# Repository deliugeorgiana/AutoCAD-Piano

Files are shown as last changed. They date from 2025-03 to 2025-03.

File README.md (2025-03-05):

# AutoCAD-Piano
This project features a detailed 3D model of an upright piano, created in AutoCAD. 
It includes both external components and internal mechanisms, offering a realistic representation of the instrument's structure. 

📌 Key Features:

Detailed 3D model of an upright piano
Includes external components (case, keys, pedals)
Includes internal components (hammers, strings, dampers)
Realistic rendering for a clear visualization
The project was created to explore the technical design of a piano and improve 3D modeling skills in AutoCAD.

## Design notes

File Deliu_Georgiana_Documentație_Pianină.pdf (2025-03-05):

UNIVERSITATEA DIN BUCUREȘTI

FACULTATEA DE MATEMATICĂ ȘI INFORMATICĂ

DEPARTAMENTUL CALCULATOARE ȘI TEHNOLOGIA INFORMAȚIEI

PROIECT

PROIECTARE ASISTATĂ DE CALCULATOR

COORDONATOR ȘTIINȚIFIC

LECTOR DR. DRĂGAN MIHĂIȚĂ

STUDENT:

DELIU GEORGIANA

BUCUREȘTI, 2024

UNIVERSITATEA DIN BUCUREȘTI

FACULTATEA DE MATEMATICĂ ȘI INFORMATICĂ

DEPARTAMENTUL CALCULATOARE ȘI TEHNOLOGIA INFORMAȚIEI

PIANINĂ

(PIAN VERTICAL)

COORDONATOR ȘTIINȚIFIC

LECTOR DR. DRĂGAN MIHĂIȚĂ

STUDENT:

DELIU GEORGIANA

BUCUREȘTI, 2024

Cuprins

### 1. Introducere

### 1.1. Aplicație

Proiectul ”Pianină” a fost realizat in aplicația Autodesk AutoCAD 2024. Salvarea

fișierelor a fost făcută în fișiere tip .dwg, în versiunea Autocad 2018 (OP – Options > Open

and Save > Save as: AutoCAD 2018/LT2018 Drawing).

1.2.Motivație

Conform lui Tom Lehrer, ”Viața este ca un pian. Ce obții din ea depinde de modul

în care o joci". Aceasta este o afirmație profundă ce deschide o poartă spre reflecție și

introspecție asupra modului în care ne trăim viețile. Asemănarea dintre viață și un pian

sugerează că suntem protagoniștii propriei noastre povești, iar felul în care ne gestionăm

alegerile și acțiunile determină rezultatele pe care le obținem. Acesta este și motivul pentru

care am învățat să cânt la acest instrument, care te face să te simți fericit, indiferent de ce ți

se întâmplă în viața cotidiană.

În această optică, construirea unei pianine devine o alegere simbolică în care voi

putea explora și înțelege mai profund mesajul acestui citat. Prin proiectarea unei pianine,

voi intra într-o relație directă cu procesul de creație și cu ideea de a da viață unui instrument

muzical, voi fi ca un pianist care își compune propriul său concert. Fiecare pas în construcția

pianinei reprezintă o notă muzicală în partitura vieții umane. Alegerea mărimilor si a layer-

elor reflectă alegerile și valorile mele, precum și felul în care vreau să-mi exprim esența și

aspirațiile.

Prin această experiență, avem de invățat că viața nu este doar despre a trăi pasiv, ci

despre a fi creatori activi ai propriului nostru destin. La fel cum un pianist trebuie să practice

și să-și perfecționeze abilitățile pentru a interpreta o melodie frumoasă, și noi trebuie să fim

dedicați în a ne dezvolta și îmbunătăți în mod continuu.

Construirea unei pianine îmi va oferi, de asemenea, ocazia de a mă conecta cu

muzica într-un mod mai profund, deaorece voi învăța despre mecanismele interne ale

acestui instrument muzical, fiecare componentă contribuind la întregul armonios al

acesteia.

Prin experiența de a crea, ne amintim că suntem cei care conducem orchestra vieții

noastre și că frumusețea și armonia depind de modul în care interpretăm partitura noastră

personală.

1.3.Istoric

Pianina (Fig.1) - o variantă mai mică a pianoforte-ului (Fig.2). La rândul său,

clavicordul și clavecinul sunt considerate a fi predecesorii pianoforte-ului. Acest instrument

a fost creat special pentru muzică de cameră în spații mici. Pianul - în italiană "pianino" -

se traduce ca "un pian mic". Spre deosebire de pianul original, în cazul pianinei, coardele,

cutia de rezonanță și mecanismul sunt dispuse vertical, astfel încât ocupă mult mai puțin

spațiu în cameră. Și acest lucru este important, deoarece în timp, instrumentele și muzica

au devenit mai accesibile populației obișnuite. Datorită dimensiunilor compacte, sunetul

pianului este mai puțin puternic decât cel al pianului de concert. Primul pian a fost creat în

1709 de către meșterul italian Bartolomeo Cristofori. El a luat ca bază carcasa clavecinului

și mecanismul de taste al clavicordului. Acest eveniment a dus la apariția pianului.

Figură 1.1. Pianină [1]

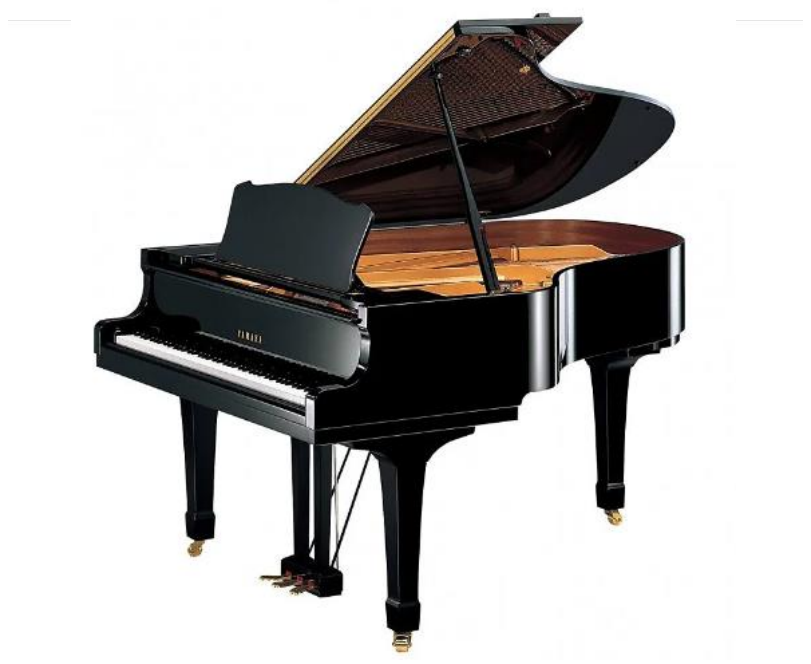
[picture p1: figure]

Figură 1.2. Pianoforte [2]
În anul 1800, americanul J. Hawkins a inventat prima pianină din lume. În 1801, o

construcție similară, dar deja cu pedale, a fost creată de către M. Müller din Australia. Cu

toate acestea, pianina arăta complet diferit pe atunci, față de modul în care societatea îl

cunoaște acum. Forma modernă a fost adoptată de abia la mijlocul secolului al XIX-lea.

Pianina a fost atât de iubită, încât acest instrument a continuat să fie îmbunătățit timp de aproape trei sute de ani. În secolul al XX-lea, au apărut pianul electronic și

sintetizatorul, cunoscute multora. Se pare că, odată cu nașterea acestui instrument, s-au născut și artiștii care să creeze capodopere pe el. În orice caz, pentru ca muzica acestui

instrument neobișnuit să aducă plăcere, trebuie să îl iubim, să îl simțim, să îl înțelegem.

Ideea unui pian vertical a apărut ca o evoluție a designului pianului. În timp ce pianul

cu coadă era preferat pentru calitățile sale sonore și performanțele de concert, acesta era

uneori prea mare și prea costisitor pentru spațiile mai mici sau pentru cei care nu puteau să

își permită un pian cu coadă.

În secolele care au urmat, diferiți constructori de instrumente muzicale au continuat

să îmbunătățească și să dezvolte designul pianinei. În secolul al XIX-lea, avansările

tehnologice și inovațiile în construcția instrumentelor au permis producția în masă a

pianinelor, făcându-le accesibile unui număr mai mare de oameni. Tot atunci, a apărut și

pianul ”Girafă” (Fig.1.3).

Un moment crucial în istoria pianinei a fost introducerea mecanismului de acțiune directă

(Fig.1.4) în anii 1820, ceea ce a îmbunătățit semnificativ calitatea sunetului și a făcut pianina mai

plăcută și mai ușor de jucat. Această inovație a condus la popularitatea crescândă a pianinei ca

instrument de uz casnic și în sălile de clasă.

Figură 1.3. Pianul "Girafa" [3]

Figură 1.4. Mecanism de acțiune [4]

Astfel, istoricul pianinei reflectă o evoluție continuă a acestui instrument muzical, de la

primele sale apariții până în prezent, adaptându-se cerințelor și tendințelor din domeniul muzical

și al designului instrumentelor.

### 2. Proiectarea pianinei

2.1.Setare Layere

Am creat 36 Straturi, care pot fi vizualizate în tabelul de mai jos:

Nr. Layer | Nume Layer | Culoare Layer | Stil linie | Grosime linie
1. | Clapă albă 2D | 254 | Continuă | 1 mm
2. | Clapă albă 3D | 255 | Continuă | 1 mm
3. | Clapă neagră 2D | 251 | Continuă | 1 mm
4. | Clapă neagră 3D | 250 | Continuă | 1 mm
5. | Corp principal 2D | 31 | Continuă | 1 mm
6. | Corp principal 3D | 17 | Continuă | 1 mm
7. | Mecanism de închidere 2D | 201 | Continuă | 1 mm
8. | Mecanism de închidere 3D | 215 | Continuă | 1 mm
9. | Pedală 2D | 151 | Continuă | 1 mm
10. | Pedală 3D | 167 | Continuă | 1 mm
11. | Roată 2D | 211 | Continuă | 1 mm
12. | Roată 3D | 45 | Continuă | 1 mm
13. | Scăunel | 15 | Continuă | 1 mm
14. | Sârmă de mână 2D | 51 | Continuă | 1 mm
15. | Sârmă de mână 3D | 50 | Continuă | 1 mm
16. | Mecanism de acțiune 2D | 33 | Continuă | 1 mm
17. | Mecanism de acțiune 3D | 35 | Continuă | 1 mm
18. | Material amortizator | 84 | Continuă | 1 mm
19. | Linguriță amortizatoare | 51 | Continuă | 1 mm
20. | Coardă 2D | 31 | Continuă | 1 mm
21. | Coardă 3D | 41 | Continuă | 1 mm
22. | Șurub 2D | 21 | Continuă | 1 mm
23. | Șurub 3D | 11 | Continuă | 1 mm
24. | Bară de presiune 2D | 111 | Continuă | 1 mm

25. | Bară de presiune 3D | 110 | Continuă | 1 mm
26. | Zăbrele acordare 2D | 131 | Continuă | 1 mm
27. | Zăbrele acordare 3D | 140 | Continuă | 1 mm
28. | Punte lungă 2D | 202 | Continuă | 1 mm
29. | Punte lungă 3D | 192 | Continuă | 1 mm
30. | Pini de ancorare 2D | 241 | Continuă | 1 mm
31. | Pini de ancorare 3D | 243 | Continuă | 1 mm
32. | Cadru 2D | 91 | Continuă | 1 mm
33. | Cadru 3D | 93 | Continuă | 1 mm
34. | Placă de rezonanță 2D | 41 | Continuă | 1 mm
35. | Placă de rezonanță 3D | 43 | Continuă | 1 mm
36. | DEFPOINTS | 171 | Continuă | 1 mm

### 2.2. Componente externe

Înainte de a începe această lucrare, am setat Workspace-ul pe ”Drafting and Annotation”,

am deselectat opțiunea de salvare automată, cu ajutorul funcției (Options > Open and Save >

deselectare Automatic Save), iar după aceea am schmibat unitățile în măsura de centimetri

(UNITS > cemtimeters).

Figură 2.1 Setare UNITS

Figură 2.2. Setarea Workspace-ului

### 2.2.1. Clapa albă și clapa neagră

Am început să lucrez, făcând schița 2D a unei clape albe și a uneia negre, cu dimensiunile

luate de la pianul meu. Inițial am făcut clapa albă, folosind Layer-ul ”Clapă albă 2D”, cu funcția

Rectangle, prima latură având lungimea de 14,5 cm, iar cea de-a doua 2,3 cm (RECTANGLE >

14.5 > Tab > 2.3 > Enter). După aceea, am setat Layer-ul ”Clapă neagră 2D”, și utilizând funcția

OFFSET, la o distanță de 0,5 cm față de latura stângă a dreptunghiului alb, am creat o linie de

ajutor. (OFFSET > 0.5 > Apasăm pe linia din partea stângă > O mutăm în partea stângă > Enter).

Acum, din colțul de sus al liniei de ajutor , cu ajutorul funcției Rectangle facem un dreptunghi

cu dimensiunile 1 cm și 9 cm (RECTANGLE > 1 > Tab > 9 > Enter). Pentru a putea fi văzute

toate dimensiunile în figură, am utilizat funcția LINEAR.

După ce am terminat schița 2D, am schimbat Worksapce-ul în 3D Basics și am schimbat

Layerul de lucru în ”Clapă albă 3D”. Pentru a delimita obiectul, am utilizat funcția

BOUNDARY(BOUNDARY > REGION > Selectăm mijlocul schiței > Enter). Lățimea clapei

albe este de 2 cm. Am folosit funcția EXTRUDE (EXTRUDE > Selectăm dreptunghiul mare >

2 > Enter). Acum selectăm stratul ”Clapă neagră 3D”. Pentru a delimita obiectul, am utilizat

funcția BOUNDARY(BOUNDARY > REGION > Selectăm mijlocul schiței > Enter). Lățimea

clapei negre este de 1 cm. Folosim funcția EXTRUDE (EXTRUDE > Selectăm dreptunghiul

mare > 1 > Enter).

Figura 2.3. Clapa albă și clapa neagră 2D

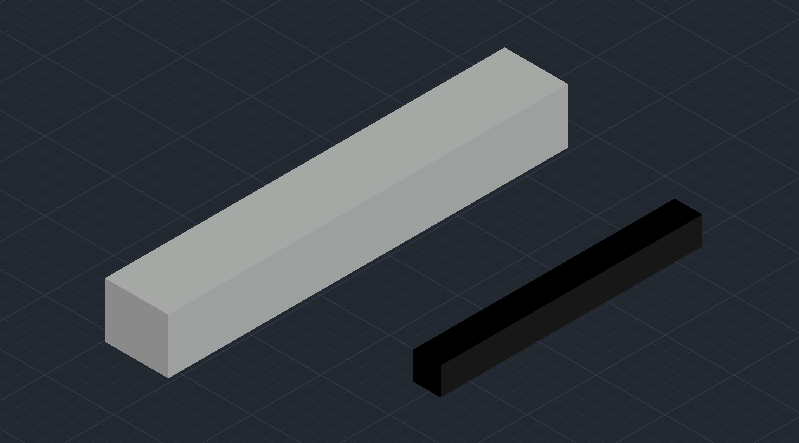
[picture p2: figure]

### 2.2.2. Placă superioară

Înainte de a mă apuca de lucru, am creat cele 2 Layere pe care le-am folosit mai apoi. Primul

a fost ”Corp principal 2D”. Cu ajutorul funcției RECTANGLE, am creat un dreptunghi, prima

latură având lungimea de 19 cm, iar cea de-a doua 150 cm (RECTANGLE > 19 > Tab > 150 >

Enter). Am selectat Layer-ul ”Element de distanțare” și am apăsat pe funcția OFFSET, plecând de

la latura inferioară de 150 cm a dreptunghiului, pe o distanță de 1cm (OFFSET > 1 > Apasăm pe

latura inferioară a dreptunghiului > O mutăm în jos > Enter). După aceea, folosin funcția LINE,

unim capetele cu cele ale dreptunghiului (LINE > 1 > , > 90). Mai folosim încă o dată funcția

OFFSET, dar de data aceasta, de la linia de jos, în sus, pe o distanță de 1 cm (OFFSET > 1 >

Apăsăm pe linia de jos > O mutăm în sus > Enter). Setăm iar Layer-ul ”Corp principal 2D”, folosim

OFFSET pe o distanță de 0,5 cm față de ultima linie și o tragem în sus (OFFSET > 0.5 > Apăsăm

pe ultima linie folosită > O mutăm în sus > Enter). Cu ajutorul funcției MIRROR, selectăm

dreptunghiul de sus, și îl oglindim față de noua linie creată (MIRROR > Selectăm entitatea

dreptunghi > Space > Selectăm Middle Point > Space > Fixăm entitatea oglindită > No > Enter). Ștergem linia de ajutor cu ajutorul comenzii ERASE. În final, am adăugat și dimensiunile, care pot

fi observate și în figura 2.5.

Figura 2.4 Clapa albă și clapa neagră 3D

FIgura 2.5. Placă superioară 2D

După ce am terminat schița 2D, am schimbat Worksapce-ul în 3D Basics și am schimbat

Layerul de lucru,”Corp principal 3D”. Pentru a delimita obiectul, am utilizat funcția BOUNDARY

(BOUNDARY > REGION > Selectăm mijlocul schiței > Enter). Lățimea obiectului este de 1 cm,

iar a celui din mijloc de 1.3 cm. Am folosit funcția EXTRUDE (EXTRUDE > Selectăm conturul

> 1 > Selectăm dreptunghiul mic > 1.3 > Enter).

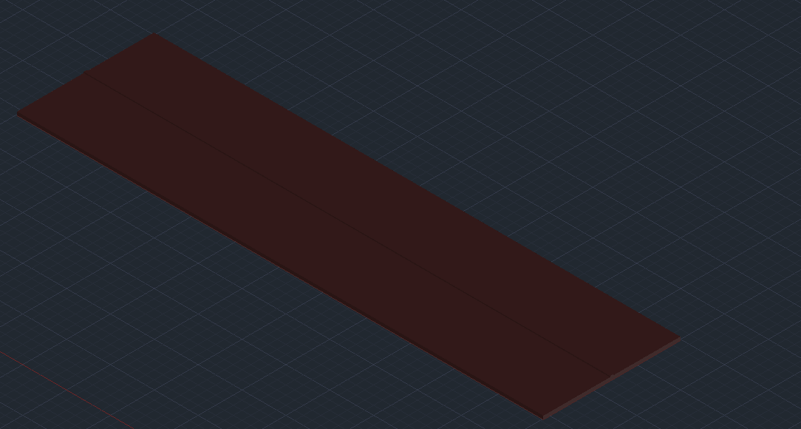
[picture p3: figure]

Figură 2.6. Placă superioară 3D

### 2.2.3. Capac

Înainte de a începe să fac schița 2D, am setat Straturile ”Corp principal 2D” și ”Mecanism de

închidere 2D”. Pentru a face viziunea frontală, am început cu un dreptungi (RECTANGLE > 135

> Tab > 20 > Enter). Am folosit funcția EXPLODE, spărgând astfel dreptunghiul în 4 bucăți.

Pentru a mai trasa o linie de lungimea celei de sus, am utilizat funcția OFFSET (OFFSET > 2 >

Apasăm pe linia de sus > O mutăm în jos > Enter). La o distanță de 4 cm față de linia de jos, am creat un dreptunghi. (RECTANGLE > 42 > Tab > 2 > Enter). În dreapta acestui dreptunghi, am făcut altul. (RECTANGLE > 4 > Tab > 1 > Enter). Pentru a face același dreptunghi și pe partea

stângă, am utilizat funcția MIRROR (MIRROR > Selectăm entitatea dreptunghi > Space >

Selectăm Middle Point > Space > Fixăm entitatea oglindită > No > Enter). Selectăm stratul

”Mecanism de închidere 2D” și între cele două linii de sus, facem un dreptunghi (RECTANGLE > 1 > Tab > 8 > Enter). În interiorul acestuia, facem alt dreptunghi (RECTANGLE > 0.4 > Tab >2 >

Enter). La o distanță de 0.6 cm față de latura din drepata a dreptunghiului exterior, am facut un

cerc (CIRCLE > RADIUS > 0.2 > Enter). Cu ajutorul funției MIRROR, l-am oglindit (MIRROR

> Selectăm entitatea cerc > Space > Selectăm Middle Point > Space > Fixăm entitatea oglindită >

No > Enter). Finalizând aceste acțiuni, am obținut vederea din față a capacului.

Figura 2.7. Capac 2D, Vedere frontală

Pentru a face vederea laterală, am selectat stratul ”Corp principal 2D”. Cu ajutorul funcției

POLYLINE, am creeat urmatoarea entitate. (POLYLINE > 2 > Space > 5 > Space > 18 > Space >

2 > Space > 20 > Space > 7). La o distanță de 7 cm începând de la bază, am făcut un dreptunghi

(RECTANGLE > 1 > Tab > 7 > Enter). Folosind funcția OFFSET, trasăm niște linii (OFFSET >

0,5 > Apasăm pe linia din capătul stâng > O mutăm în dreapta > Enter > Repetăm). Pentru a mai

trasa o linie, folosim aceeași funcție (OFFSET > 1 > Apasăm pe linia din dreapta > O mutăm în

stânga > Enter). La o distanță de 3.05 față de latura dreaptă, facem un dreptunghi (RECTANGLE

> 0.2 > Tab > 0.9 > Enter). La o distanță de 1 cm față de mijlocul inferior al dreptunghiului, copiem

entitatea în stânga și în drepata (COPY > Selectăm dreptunghiul > 1 > Enter).

Figura 2.8. Capac 2D, Vedere laterală

După ce am terminat schița 2D, am schimbat Worksapce-ul în 3D Basics și am schimbat

Layerul de lucru, și anume ” Corp principal 3D”. Pentru a delimita toate zonele necesare, am utilizat

funcția BOUNDARY (BOUNDARY > REGION > Selectăm toate zonele desenului > Enter).

Vederea laterală ne este de ajutor pentru a vedea lățimea obiectelor, astfel începem să înalțăm toate

piesele.Pentru partea de sus, folosim următoarea funcție (PRESSPULL > 7 >Space > Space > 7.5

> Space > 7.5 > Space > 7.5). Pentru partea de jos (PRESSPULL > 2 > Space > 7 > Space > 7 >

Space > 7). Pentru a adăuga și suportul de portativ, facem un dreptunghi (RECTANGLE > 2 > Tab

> 42 > Enter). După aceea, îl copiem, pentru a mai forma 2 dreptunghiuri asemănătoare (COPY >

Selectăm dreptunghiul > 2 > Enter > Repetăm). După aceea, le selectăm și utilizăm functia

3DROTATE, la un unghi de 90°. Cu ajutorul funcției MOVE, selectăm cele 3 dreptungiuri și le

mutăm. După aceea, folosim functia EXTRUDE, la nivel de 0.5 cm.

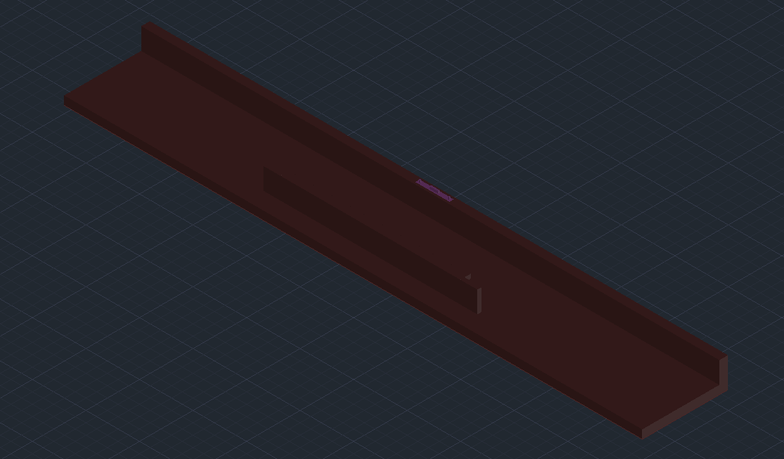
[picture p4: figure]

Figura 2.9. Capac 3D

### 2.2.4. Braț lateral

Am schimbat Workspace-ul în Drafting & Annotation, am setat stratul ” Corp principal 2D ”.

Pentru viziunea laterală am utilizat funcția POLYLINE (POLYLINE > 12 > Space > 30 > Space >

17 > Space > 2.5 > Space > 5 > Space > 2.5 > Space > 25 > Enter). Pentru a face o zonă rotunjită,

folosim funcția TAN, TAN, RADIUS, cu raza cercului de 7 cm. (TAN > TAN > 7 > rotunjită,

folosim funcția TAN, TAN, RADIUS, cu raza cercului de 7 cm. (TAN > TAN > 7 > Enter). Pentru

a rotunji zona din partea de stânga sus, folosim funcția FILLET (FILLET > r > 3 > Enter).

Figura 2.10. Braț lateral 2D, Vedere lateral

Pentru a face vederea frontală, am utilizat funcția de dreptunghi (RECTANGLE > 17 > Tab > 4 >Enter).

Figura 2.11. Braț lateral 2D, Vedere Frontală

După ce am terminat schița 2D, am schimbat Worksapce-ul în 3D Basics și am schimbat Layerul

de lucru, ” Corp principal 3D ”. Pentru a delimita obiectul, am utilizat funcția

BOUNDARY(BOUNDARY > REGION > Selectăm mijlocul schiței > Enter). Vederea laterală ne

este de ajutor pentru a vedea lățimea acestui obiect, și anume de 4 cm. Am folosit funcția

EXTRUDE (EXTRUDE > Selectăm obiectul > 4 > Enter). Pentru a roti obiectul, am folosit funcția

3DROTATE (Selectăm obiectul > Apelăm funcția 3DROTATE > Ridicăm pe verticală la 90° >

Rotim pe orizontală spre dreapta la 90° > Enter).

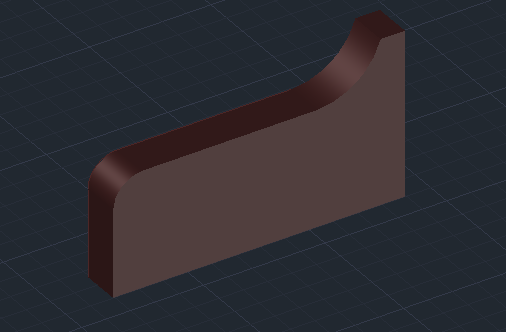
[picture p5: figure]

Figura 2.12. Braț lateral 3D

### 2.2.5. Placă laterală

Am schimbat Workspace-ul în Drafting & Annotation, am setat stratul ” Corp principal 2D

”. Pentru viziunea laterală am utilizat funcția POLYLINE (POLYLINE > 55 > Space > 118 > Space

> 35 > Space > 109 > Space > 20 > Space > 9 > Enter ). Pentru a face vederea frontală, am utilizat

funcția de dreptunghi (RECTANGLE > 118 > Tab > 1 >Enter).

Figura 2.13. Placă laterală 2D

După ce am terminat schița 2D, am schimbat Worksapce-ul în 3D Basics și am schimbat Layerul

de lucru, ” Corp principal 3D ”. Pentru a delimita obiectul, am utilizat funcția

BOUNDARY(BOUNDARY > REGION > Selectăm mijlocul schiței > Enter). Vederea laterală ne

este de ajutor pentru a vedea lățimea acestui obiect, și anume de 1 cm. Am folosit funcția

EXTRUDE (EXTRUDE > Selectăm obiectul > 1 > Enter). Pentru a roti obiectul, am folosit funcția

3DROTATE (Selectăm obiectul > Apelăm funcția 3DROTATE > Ridicăm pe verticală la 90° >

Rotim pe orizontală spre dreapta la 90° > Enter).

Figura 2.14. Placă laterală 3D

### 2.2.6. Placă frontală interioară

Înainte de a începe să fac schița 2D, am setat stratul ”Corp principal 2D ”. Pentru a face

viziunea laterală, am început cu un dreptunghi (RECTANGLE > 132 > Tab > 47 > Enter). După

aceea, pentru a face pianina vizual mai frumoasă, am mai facut un dreptunghi, in mijlocul celui

precedent (RECTANGLE > 123 > Tab > 37 > Enter).

Pentru a face vederea laterală, am utilizat funcția de creare a unui dreptunghi

(RECTANGLE > 47 > Tab > 1 > Enter). Mai facem un dreptunghi (RECTANGLE > 37 > Tab >

1.5 > Enter), pe care îl mutăm la mijlocul primului dreptunghi. Pentru a înlătura surplusul, folosim

funcția TRIM.

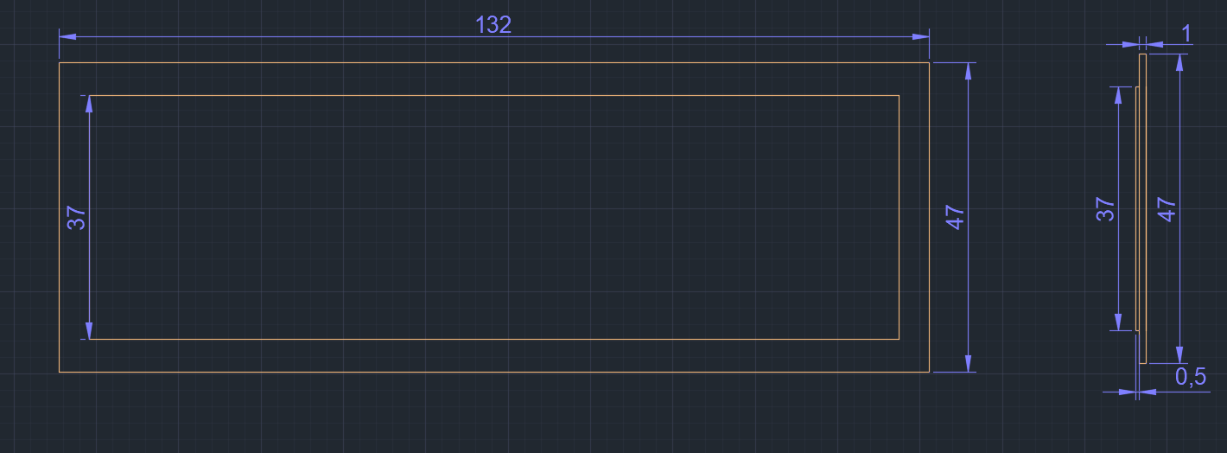
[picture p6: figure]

Figura 2.15. Placă frontală interioară 2D

După ce am terminat schița 2D, am schimbat Worksapce-ul în 3D Basics și am schimbat

Layerul de lucru,” Corp principal 3D ”. Pentru a delimita obiectul, am utilizat funcția

BOUNDARY(BOUNDARY > REGION > Selectăm mijlocul schiței > Enter). Vederea laterală ne

este de ajutor pentru a vedea lățimea acestor dreptunghiuri, și anume de 1 cm, respectiv 1.5 cm.

Am folosit funcția EXTRUDE (EXTRUDE > Selectăm dreptunghiul mic > 1.5 > Enter),

(EXTRUDE > Selectăm dreptunghiul mare > 1 > Enter). Pentru a roti obiectul, am folosit funcția

3DROTATE (Selectăm obiectul > Apelăm funcția 3DROTATE > Ridicăm pe verticală la 90° >

Enter).

Figura 2.16. Placă frontală interioară 3D

### 2.2.7. Placă inferioară

Înainte de a începe să fac schița 2D, am setat stratul ”Corp principal 2D ”. Pentru a face viziunea

laterală, am început cu un dreptungi (RECTANGLE > 133 > Tab > 9 > Enter). După aceea, pentru a evidenția locul în care se vor afla pedalele, am trasat niște linii punctate. Pentru a face vederea

laterală, am utilizat funcția de dreptunghi (RECTANGLE > 1.5 > Tab > 9 > Enter).

Figură 2.17. Placă inferioară 2D

După ce am terminat schița 2D, am schimbat Worksapce-ul în 3D Basics și am schimbat

Layerul de lucru, ”Corp principal 3D ”. Pentru a delimita obiectul, am utilizat funcția

BOUNDARY(BOUNDARY > REGION > Selectăm mijlocul schiței > Enter). Vederea laterală ne

este de ajutor pentru a vedea lățimea obiectului, și anume de 1.5 cm. Am folosit funcția EXTRUDE

(EXTRUDE > Selectăm dreptunghiul > 1.5 > Enter). Pentru a roti obiectul, am folosit funcția

3DROTATE (Selectăm obiectul > Apelăm funcția 3DROTATE > Ridicăm pe verticală la 90° >

Enter).

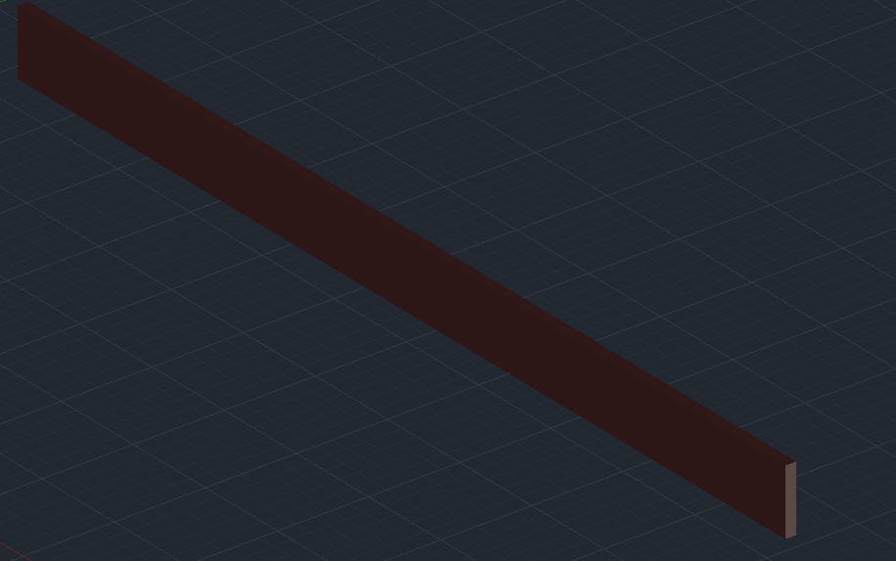
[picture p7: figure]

Figura 2.18. Placă inferioară 3D

### 2.2.8. Placă frontală superioară

Înainte de a începe să fac schița 2D, am setat stratul ”Corp principal 2D ”. Pentru a face

viziunea laterală, am început cu un dreptungi (RECTANGLE > 135 > Tab > 38 > Enter). Pentru a face vederea laterală, am utilizat funcția de dreptunghi (RECTANGLE > 1.5 > Tab> 38 >Enter).

Figura 2.19. Placă frontală superioară 2D

După ce am terminat schița 2D, am schimbat Worksapce-ul în 3D Basics și am schimbat

Layerul de lucru, ”Corp principal 3D”. Pentru a delimita obiectul, am utilizat funcția

BOUNDARY(BOUNDARY > REGION > Selectăm mijlocul schiței > Enter). Vederea laterală ne

este de ajutor pentru a vedea lățimea obiectului, de 1.5 cm. Am folosit funcția EXTRUDE

(EXTRUDE > Selectăm dreptunghiul > 1.5 > Enter). Pentru a roti obiectul, am folosit

funcția3DROTATE (Selectăm obiectul > Apelăm funcția 3DROTATE > Ridicăm pe verticală la

90° > Enter).

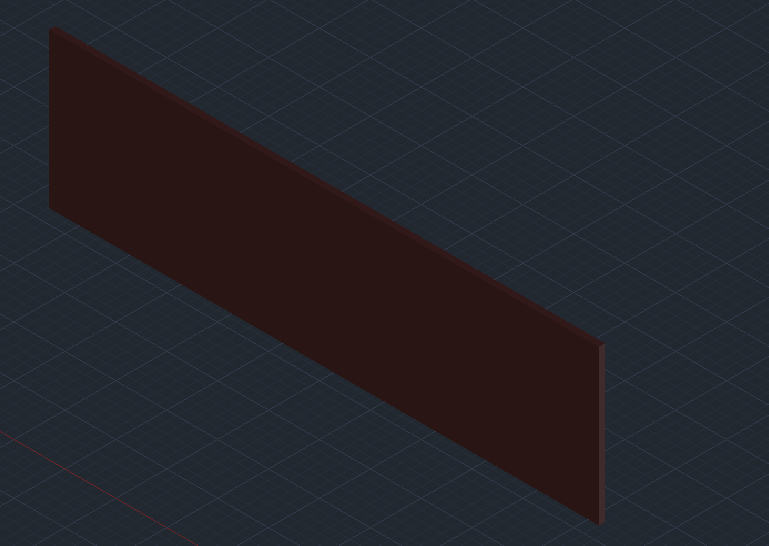
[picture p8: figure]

Figură 2.20. Placă frontalăn superioară 3D

### 2.2.9. Bloc de clape

Înainte de a începe să fac schița 2D, am setat stratul ”Corp principal”. Pentru a face viziunea de

sus, am început cu un dreptungi (RECTANGLE > 135 > Tab > 15.5 > Enter).

Pentru a face vederea laterală, am utilizat funcția de dreptunghi (RECTANGLE > 1.5 > Tab >

38 >Enter). Am folosit funcția EXPLODE, spărgând astfel dreptunghiul în 4 bucăți. Pentru a mai

trasa o linie de lungimea celei din stânga, am utilizat funcția OFFSET (OFFSET > 11 > Apasăm

pe linia de sus > O mutăm în dreapta > Enter), iar pentru linia din partea dreaptă am utilizat aceeași

funcție (OFFSET > 7 > Apasăm pe linia din dreapta > O mutăm în stânga > Enter).

Pentru a face vederea frontală, am utilizat funcția de dreptunghi (RECTANGLE > 2.5 > Tab >135

>Enter).

Figura 2.21. Bloc de clape 2D

După ce am terminat schița 2D, am schimbat Worksapce-ul în 3D Basics și am schimbat

Layerul de lucru,”Corp principal 3D”. Pentru a delimita obiectul, am utilizat funcția

BOUNDARY(BOUNDARY > REGION > Selectăm mijlocul schiței > Enter). Vederea frontală ne

este de ajutor pentru a vedea lățimea obiectului, de 2.5 cm. Am folosit funcția EXTRUDE

(EXTRUDE > Selectăm dreptunghiul > 2.5 > Enter).

Figură 2.21. Bloc de clape 3D

### 2.2.10. Înveliș pentru clape

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

viziunea de sus, am început cu un dreptunghi (RECTANGLE > 135 > Tab > 2.5 > Enter). În

mijlocul acestuia, am făcut un alt dreptunghi (RECTANGLE > 1 > Tab > 8 > Enter). La rândul

său, acesta conține un dreptunghi, amplasat tot în centru (RECTANGLE > 1.6 > Tab > 0.3 > Enter).

La o distanță de 0.9 cm față de latura stângă a celui mai mic dreptunghi, facem un cerc (CIRCLE

> RADIUS > 0.3 >Enter). Pentru a-l oglindi, utilizăm funcția MIRROR (MIRROR > Selectăm

entitatea cerc > Space > Selectăm Middle Point > Space > Fixăm entitatea oglindită > No > Enter).

Figura 2.23. Înveliș pentru clape 2D

După ce am terminat schița 2D, am schimbat Worksapce-ul în 3D Basics și am schimbat

Layerul de lucru,” Corp principal 3D”. Pentru a delimita obiectul, am utilizat funcția

BOUNDARY(BOUNDARY > REGION > Selectăm fiecare zonă a schiței > Enter). Vederea

frontală ne este de ajutor pentru a vedea lățimea obiectului principal, de 0.5 cm, iar elementele mici

de 1.5, și cel de legătură de 1 cm. Am folosit funcția EXTRUDE (EXTRUDE > Selectăm

dreptunghiul mare > 0.5 > Enter), (EXTRUDE > Selectăm dreptunghiul mic > 1 > Enter),

(EXTRUDE > Selectăm cercurile și dreptunghiul > 1.5 > Enter).

### 2.2.11. Picior

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

viziunea de sus, am început cu un dreptungi (RECTANGLE > 40 > Tab > 4 > Enter). Deasupra

acestuia, am mai facut un dreptunghi (RECTANGLE > 5 > Tab > 0.5 > Enter). Pentru a oglindi

acest dreptunghi, am utilizat funcția MIRROR (MIRROR > Selectăm entitatea dreptunghi > Space

> Selectăm Middle Point > Space > Fixăm entitatea oglindită > No > Enter).

Figura 2.25. Picior 2D

După ce am terminat schița 2D, am schimbat Worksapce-ul în 3D Basics și am schimbat

Layerul de lucru, ”Corp principal 3D”. Pentru a delimita obiectul, am utilizat funcția

BOUNDARY(BOUNDARY > REGION > Selectăm mijlocul schiței > Enter). Vederea laterală ne

este de ajutor pentru a vedea lățimea obiectului, de 5 cm. Am folosit funcția EXTRUDE

(EXTRUDE > Selectăm dreptunghiurile > 5 > Enter). Pentru a roti obiectul, am folosit funcția

3DROTATE (Selectăm obiectul > Apelăm funcția 3DROTATE > Ridicăm pe verticală la 90° >

Enter).

Figura 2.26. Picior 3D

### 2.2.12. Bloc de picior

Înainte de a începe să fac schița 2D, am setat stratul ” Corp principal 2D”. Pentru a face viziunea

laterală, am început cu un dreptungi (RECTANGLE > 21 > Tab > 9 > Enter).

Pentru vederea frontală, am utilizat, de asemenea, un dreptunghi (RECTANGLE > 6 > Tab > 9

> Enter).

Figura 2.27. Bloc de picior 2D

După ce am terminat schița 2D, am schimbat Worksapce-ul în 3D Basics și am schimbat

Layerul de lucru, ”Corp principal 3D”. Pentru a delimita obiectul, am utilizat funcția

BOUNDARY(BOUNDARY > REGION > Selectăm mijlocul schiței > Enter). Vederea frontală ne

este de ajutor pentru a vedea lățimea obiectului, de 6 cm. Am folosit funcția EXTRUDE

(EXTRUDE > Selectăm dreptunghiurile > 6 > Enter). Pentru a roti obiectul, am folosit funcția

3DROTATE (Selectăm obiectul > Apelăm funcția 3DROTATE > Ridicăm pe verticală la 90° >

Rotim pe orizontală la 90° > Enter).

Figura 2.28. Bloc de picior 3D

### 2.2.13. Pedală

Înainte de a începe să fac schița 2D, am setat stratul ” ”. Pentru a face viziunea de sus, am

început cu un dreptungi (RECTANGLE > 3 > Tab > 3.5 > Enter). Deasupra acestuia, am mai facut

un dreptunghi (RECTANGLE > 4 > Tab > 0.5 > Enter). La sfârșitul dreptunghiului mare, am facut

un cerc (CIRCLE > RADIUS > 1.5 > Enter). Pentru a înlătura liniile ce erau în plus, am utilizat

funcția TRIM.

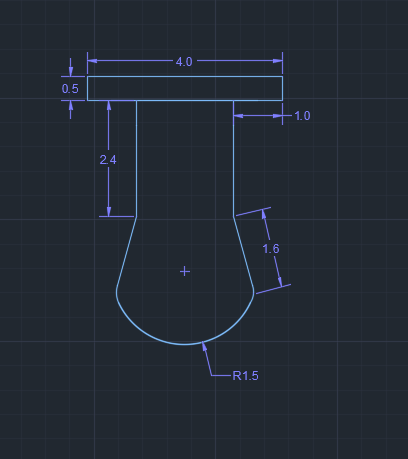
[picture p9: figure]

Figura 2.29. Pedală 2D

După ce am terminat schița 2D, am schimbat Worksapce-ul în 3D Basics și am schimbat

Layerul de lucru, ”Pedală 3D”. Pentru a delimita obiectul, am utilizat funcția

BOUNDARY(BOUNDARY > REGION > Selectăm mijlocul schiței > Enter). Lățimea obiectului

este de 3 cm. Am folosit funcția EXTRUDE (EXTRUDE > Selectăm conturul > 2 > Enter).

Figura 2.30. Pedală 3D

### 2.2.14. Roată

Înainte de a începe să fac schița 2D, am setat stratul ”Roată 2D ”. Pentru a face viziunea

laterală, am început cu un dreptungi (RECTANGLE > 4.3 > Tab > 2.3 > Enter). După aceea, facem

un cerc, cu centrul în vârful stâng de jos al dreptunghiului cerc (CIRCLE > RADIUS > 1.5 > Enter).

Surplusul îl ștergem cu ajutorul comenzii TRIM.

Pentru a face vederea frontală, am făcut un dreptunghi (RECTANGLE > 2.5 > Tab > 4.3 > Enter). În interiorul acestuia, facem un alt dreptunghi (RECTANGLE > 1.5 > Tab > 5 > Enter), pe

care îl amplasăm la o distanță de 1 cm față de primul dreptunghi. La o distanță de 2 cm față de

latura de sus, trasăm o linie de aceeași lungime, adică de 1.5 cm. Acest mini-dreptunchi va fi

împărțit în 3 părți egale, la o distanță de 0.5 cm față de pereți, cu ajutorul urmatoare funcții

(OFFSET > 0.5 > Apasăm pe linia din dreapta > O mutăm în stânga > Repetăm > Enter). Utilizăm

funcția TRIM pentru a elimina liniile de care nu avem nevoie.

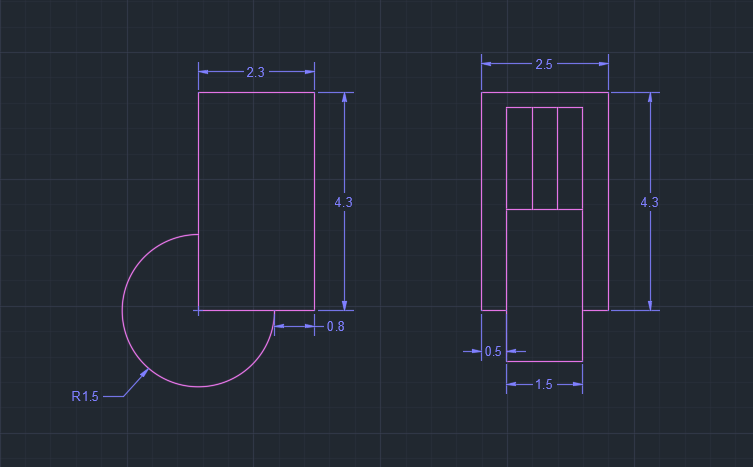
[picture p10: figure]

Figura 2.31. Roată 2D

După ce am terminat schița 2D, am schimbat Worksapce-ul în 3D Basics și am schimbat

Layerul | de | lucru,”Roată | 3D”. | Pentru | a | delimita | obiectul, | am | utilizat | funcția

BOUNDARY(BOUNDARY > REGION > Selectăm mijlocul schiței > Enter). Lățimea roții este

de 1.5 cm, iar a corpului este de 2.3 cm. Am folosit funcția EXTRUDE (EXTRUDE > Selectăm

cercul > 1.5 > Selectăm corpul > 2.3 > Enter).

Figura 2.32. Roată 3D

### 2.2.15. Scăunel

Înainte de a începe să fac schița 2D, am setat stratul ”Scăunel ”. Pentru a face vederea de

sus, am început cu un dreptungi (RECTANGLE > 54 > Tab > 30 > Enter). În interiorul acestuia

facem alt dreptunghi (RECTANGLE > 51 > Tab > 27 > Enter).

Pentru vederea frontală, am făcut inițial un dreptunghi (RECTANGLE > 51 > Tab > 2 >

Enter). Fix sub acesta, mai facem unul asemănător, dar de alte dimensiuni (RECTANGLE > 45 > Tab > 7 > Enter). În capătul din stanga, facem încă un dreptunghi (RECTANGLE > 40 > Tab > 3

> Enter). Acesta va trebui oglindit (MIRROR > Selectăm entitatea dreptunghi > Space > Selectăm

Middle Point > Space > Fixăm entitatea oglindită > No > Enter).

Pentru vederea laterală, am început cu un dreptunghi (RECTANGLE > 27 > Tab > 2 >

Enter). Repetăm aceleași proceduri, ca la vederea frontală, dar dimensiunile vor fi diferite. Primul dreptunghi: (RECTANGLE > 30 > Tab > 7 > Enter). În capătul din stânga, facem încă un dreptunghi (RECTANGLE > 40 > Tab > 3 > Enter). Folosim funcția pentru oglindire: (MIRROR

> Selectăm entitatea dreptunghi > Space > Selectăm Middle Point > Space > Fixăm entitatea

oglindită > No > Enter).

Figura 2.33. Scăunel 2D

După ce am terminat schița 2D, am schimbat Worksapce-ul în 3D Basics și am schimbat

Layerul | de | lucru, | ”Scăunel”. | Pentru | a | delimita | obiectul, | am | utilizat | funcția

BOUNDARY(BOUNDARY > REGION > Selectăm mijlocul schiței > Enter). Lățimea pernei este

de 2 cm, iar a corpului este de 3 cm. Am folosit funcția EXTRUDE (EXTRUDE > Selectăm perna

> 2 > Selectăm corpul > 3 > Enter).

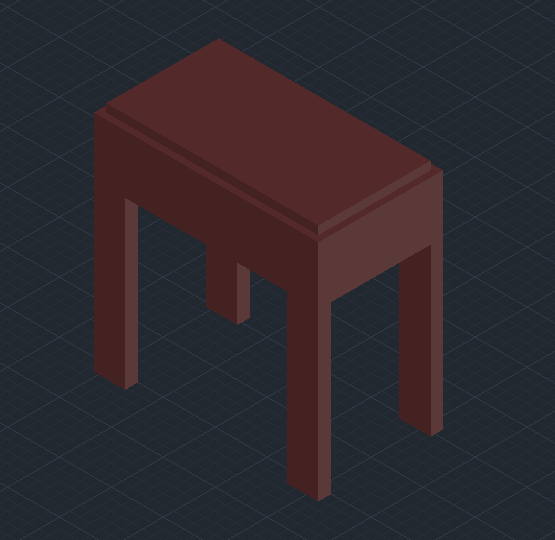
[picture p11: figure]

Figura 2.34. Scăunel 3D

### 2.3. Componente interne

### 2.3.1. Sârmă de mână

Am schimbat Workspace-ul în Drafting & Annotation, am setat stratul ” Sârmă de mână 2D ”.

Am început prin utilizarea funcției POLYLINE (POLYLINE > 6 > Space > 3.28 > Tab > 58°>

Space > 3.51 > Enter). După aceea, am făcut un cerc (CIRCLE > RADIUS > 1.03 > Enter) și am

continuat cu o linie verticala de 4.05 cm (LINE > 4.5 > Enter).

Figura 2.35. Sârmă de mână 2D

După ce am terminat schița 2D, am schimbat Worksapce-ul în 3D Basics și am schimbat Layerul de lucru, ” Sârmă de mână 3D ”. În capetele acestei polilinii, am făcut două cerculețe de

rază 0.3 cm (CIRCLE > RADIUS > 0.3 > Repetăm > Enter). După aceea, cu ajutorul funcției

SWEEP, am creat obiectul dorit (SWEEP > Selectăm cercurile > Enter > Selectăm polilinia >

Enter).

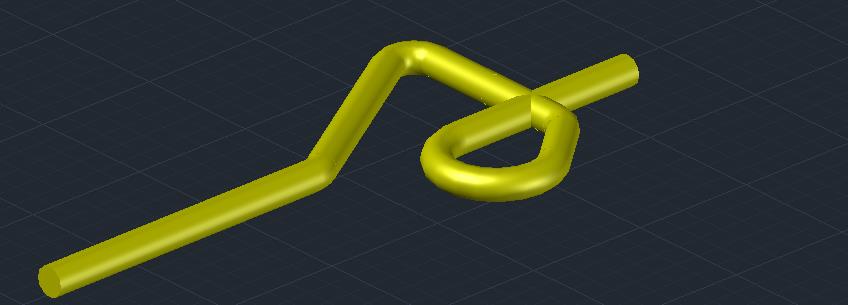
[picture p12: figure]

Figura 2.36. Sârmă de mână 3D

### 2.3.2. Mecanism de reținere (Back Check)

Am schimbat Workspace-ul în Drafting & Annotation, am setat stratul ” Metal ”. Am

început prin utilizarea funcției LINE (LINE > 14.8 > Enter). După aceea, am făcut un cerc

(CIRCLE > RADIUS > 0.2 > Enter). Am setat mai apoi stratul ”Mecanism de acționare” și am

continuat cu o polilinie orizontală de 2.5 cm (POLYLINE > 2.5 > Space > 1.5 > Space > 4.5 > Space > 4 > Space > 4.5 > Enter). Între cele 2 linii formate, am făcut un cerc, de rază 1.77 cm

(CIRCLE > RADIUS > 0.3 > Enter) și l-am unit cu linia tangenta, ce ducea spre capătul de jos.

Am folosit funcția OFFSET pentru a mai trasa o linie (OFFSET > 1.5 > Apasăm pe linia din partea

dreaptă > O mutăm în partea stângă > Enter). Dreptunghiul ce s-a format în partea dreapta va fi

sub stratul numit” Material amortizator”.

Figura 2.37. Mecanism de reținere 2D

După ce am terminat schița 2D, am schimbat Worksapce-ul în 3D Basics și am schimbat Layerul de lucru, ” Mecanism de acționare 3D ”. În capătul acestei linii, am făcut un cerculeț

derază 0.2 cm (CIRCLE > RADIUS > 0.2 > Repetăm > Enter). După aceea, cu ajutorul funcției

SWEEP, am creat obiectul dorit (SWEEP > Selectăm cercul > Enter > Selectăm linia > Enter).

Pentru a face elementul de legătură, am făcut un cerc de rază 0.2 cm la capătul obiectului și înca

unul separate, tot de aceeași dimensiune. (SWEEP > Selectăm cercul exterior > Enter > Selectăm

cercul de pe obiect > Enter). Acesta trebuie rotit, de aceea folosim funcția 3DROTATE (Selectăm

obiectul > Apelăm funcția 3DROTATE > Ridicăm pe verticală la 90° > Enter). Pentru a delimita

obiectul, am utilizat funcția BOUNDARY (BOUNDARY > REGION > Selectăm mijlocul schiței

> Enter). După aceea, am folosit funcția extrude pentru a înălța cele două dreptunghiuri la o distanță

de 2.5 cm (EXTRUDE > Selectăm dreptunghiurile > 2.5 > Enter).

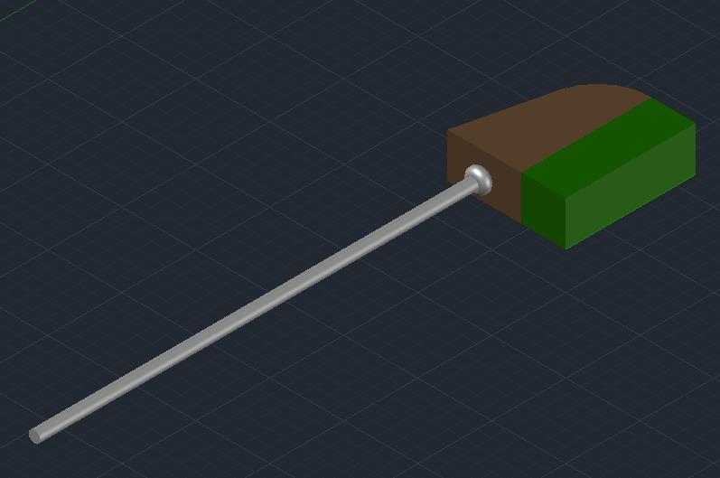
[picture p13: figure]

Figura 2.38. Mecanism de reținere 3D

### 2.3.3. Linguriță amortizatoare

Am schimbat Workspace-ul în Drafting & Annotation, am setat stratul ” Linguriță

amortizatoare ”. Am început prin utilizarea funcției POLYLINE (POLYLINE > 6.51 > Space >

12.49 > Enter). După aceea, am făcut 3 cercuri, 2 în capetele liniei și altul la distanță de 4.5 față de

începutul liniei (CIRCLE > RADIUS > 1.3 > Enter), (CIRCLE > RADIUS > 1.2 > Enter),

(CIRCLE > RADIUS > 2.2 > Enter). Liniile în plus au fost șterse cu ajutorul comenzii TRIM.

Figura 2.39. Linguriță amortizatoare 3D

După ce am terminat schița 2D, am schimbat Worksapce-ul în 3D Basics și am schimbat

stratul de lucru ” Linguriță amortizatoare”. Pentru a delimita obiectul, am utilizat funcția

BOUNDARY (BOUNDARY > REGION > Selectăm mijlocul schiței > Enter). După aceea, am

folosit funcția extrude pentru a înălța cele două dreptunghiuri la o distanță de 2 cm (EXTRUDE >

Selectăm dreptunghiurile > 2 > Enter).

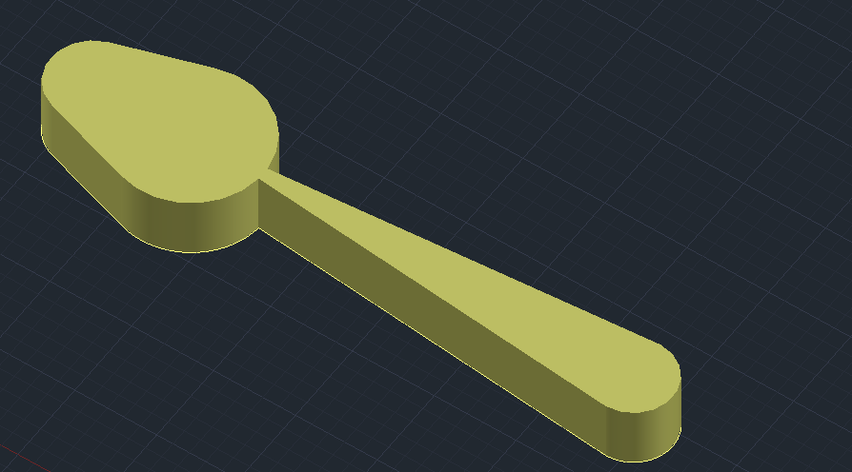
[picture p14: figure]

Figura 2.40. Linguriță amortizatoare 3D

### 2.3.4. Ciocănele

Am schimbat Workspace-ul în Drafting & Annotation, am setat stratul ”Mecanism de

acțiune”. Cu ajutorul funcției RECTANGLE, am creat un dreptunghi, prima latură având lungimea

de 2 cm, iar cea de-a doua 6 cm (RECTANGLE > 2 > Tab > 6 > Enter). La o distanță de 1 cm față

de latura superioară a dreptunghiului, am creat un cerculeț (CIRCLE > RADIUS > 0.2 > Enter).

Am utilizat funcția POLYLINE pentru a face mai departe corpul (POLYLINE > 10 > Space > 1 >

Space > 1 > Space > 0.5 > Space > 2 > Space > 0.5 > Space > 4.5 > Enter). După aceea am făcut

niște cercuri (CIRCLE > RADIUS > 2 > Enter), (CIRCLE > RADIUS > 1 > Enter). La o distanță

de 1.13 cm față de capătul din dreapta, am făcut un cerc, de rază 0.5 (CIRCLE > RADIUS > 0.5 >

Enter). Pentru a face un arc, am folosit comanda HELIX (HELIX > 0.1 > Space > 0.1 > Space > T

> Space > 15 > Enter).

Figura 2.41. Ciocănele 2D

După ce am terminat schița 2D, am schimbat Worksapce-ul în 3D Basics și am schimbat

stratul de lucru ”Mecanism de acțiune”. Pentru a delimita obiectul, am utilizat funcția

BOUNDARY (BOUNDARY > REGION > Selectăm mijlocul schiței > Enter). Pentru a face arcul,

am utilizat funția SWEEP (SWEEP > Selectăm cercul exterior de rază 0.1 cm > Enter > Selectam

arcul > Enter). Partea de jos am înălțat-o cu 0.9 cm, partea de deasupra cu 0.8 cm, iar restul cu 1

cm (EXTRUDE > Selectăm primul dreptunghi > 0.9 > Selectam al doilea dreptunghi > 0.8 >

Selectam restul > 1 > Enter).

Figura 2.42. Ciocănele 3D

### 2.3.5. Șina ciocănelelor

Am schimbat Workspace-ul în Drafting & Annotation, am setat stratul ” Mecanism de

acțiune ”. Am făcut pentru început vederea frontală, prin utilizarea funcției POLYLINE

(POLYLINE > 6 > Space > 3 > Space > 6 > Space > 1 > Space > 2.5 > Space > 1 > Space >2.5 >

Space > 1 > Enter). La o distanță de 2 cm de jos, facem un cerc (CIRCLE > RADIUS > 0.5 >

Enter).

Pentru vederea laterală, facem un dreptunghi (RECTANGLE > 2 > Tab > 6 > Enter). La o

distanță de 1 cm față de latura de sus, am făcut un cerc (CIRCLE > RADIUS > 0.5 > Enter).

După ce am terminat schița 2D, am schimbat Worksapce-ul în 3D Basics și am schimbat

stratul de lucru ”Mecanism de acțiune”. Pentru a delimita obiectul, am utilizat funcția

BOUNDARY (BOUNDARY > REGION > Selectăm mijlocul schiței > Enter). Datorită vederii

laterale, aflăm că lățimea corpului este de 2 cm, după aceea folosim funcția EXTRUDE

(EXTRUDE > Selectăm obiectul > 2 > Enter). Pentru a da găuri, utilizăm SUBSTRACT

(SUBSTRACT > Selectăm obiectul > Selectăm cercurile > Enter).

Figura 2.44. Șina ciocănelelor 3D

Figura 2.43. Șina ciocănelelor 2D

### 2.3.6. Suport mecanism

Am schimbat Workspace-ul în Drafting & Annotation, am setat stratul ” Mecanism de

acțiune ”. Am început prin utilizarea funcției POLYLINE (POLYLINE > 25 > Space > 3 > Space

> 15.5 > Space > 5 > Space > 5 > Space > 1 > Space > 1 > Enter). După ce perimetrul a fost trasat,

am făcut niște cercuri de legătură și unul la o distanță de 3 cm față de capătul drept al obiectului

(CIRCLE > RADIUS > 1.44 > Enter), (CIRCLE > RADIUS > 5 > Enter), (CIRCLE > RADIUS >

2.2 > Enter).

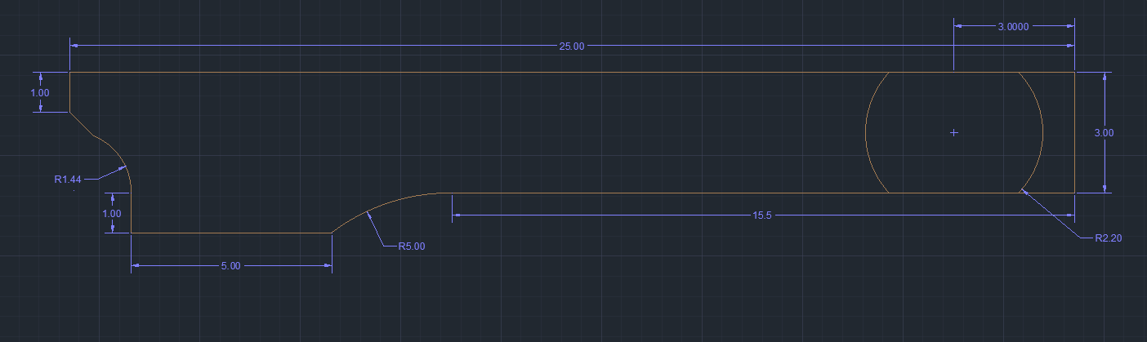
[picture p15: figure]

Figura 2.45. Suport mecansim 2D

După ce am terminat schița 2D, am schimbat Worksapce-ul în 3D Basics și am schimbat

stratul de lucru ”Mecanism de acțiune”. Pentru a delimita obiectul, am utilizat funcția

BOUNDARY (BOUNDARY > REGION > Selectăm mijlocul schiței > Enter). Cercul l-am dus la

înălțimea de 3 cm, iar restul la 4 cm (EXTRUDE > Selectăm cercul > 3 > Enter), (EXTRUDE>

Selectăm obiectul > 4 > Enter).

Figura 2.46. Suport mecanism 3D

### 2.3.7. Mecanismul de acțiune

Mecanismul de acțiune a fost realizat unind sârma de mână, mecanismul de reținere,

lingurița amortizatoare, ciocănelele, șina ciocănelelor și suportul de mecanism, ajungând în final

să arate ca în figura 2.44. Funcțiile folosite au fost: COPY și MOVE.

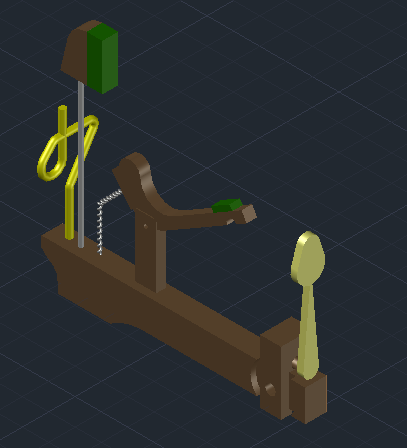
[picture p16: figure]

Figura 2.47. Mecanismul de acțiune

### 2.3.8. Corzi

Am schimbat Workspace-ul în Drafting & Annotation, am setat stratul ” Coardă 2D ”. Am utilizat funcția LINE (LINE > 170 > Enter). În capătul acestei linii, am adăugat un cerc, de rază

0.1 cm (CIRCLE > RADIUS > 0.1 > Enter).

Figura 2.48. Coardă 2D

După ce am terminat schița 2D, am schimbat Worksapce-ul în 3D Basics și am schimbat

stratul de lucru ”Coardă 3D”. Pentru a face coarda, am utilizat funcția SWEEP, având deja pregătit

cercul de rază 0.1 cm. (SWEEP > Selectăm cercul exterior > Enter > Selectăm linia > Enter).

Figura 2.49. Coardă 3D

### 2.3.9. Șurub de fixare

Am schimbat Workspace-ul în Drafting & Annotation, am setat stratul ” Șurub 2D ”. Am utilizat funcția LINE (LINE > 4 > Space > 0.5 > Enter). În continuare, facem un cerc (CIRCLE >

RADIUS > 3 > Enter). Începem să facem mici triunghiuri, după aceea le copiem, cu funcția COPY.

Pentru a face vederea de sus, am început prin a face un cerc (CIRCLE > RADIUS > 2 > Enter).

Am făcut 2 linii intersectate în mijlocul acestuia și am început să fac alte cercuri (CIRCLE >

RADIUS > 0.2 > Enter), (CIRCLE > RADIUS > 0.2 > Enter). Toate liniile care erau în plus, au fost înlăturate cu ajutorul comenzii TRIM. În jurul acestor cercuri, am trasat 3 linii (LINE > 1.13

> Space > 0.4 > Space > 1.13 > Enter). Le am oglindit de 3 ori, cu funcția MIRROR.

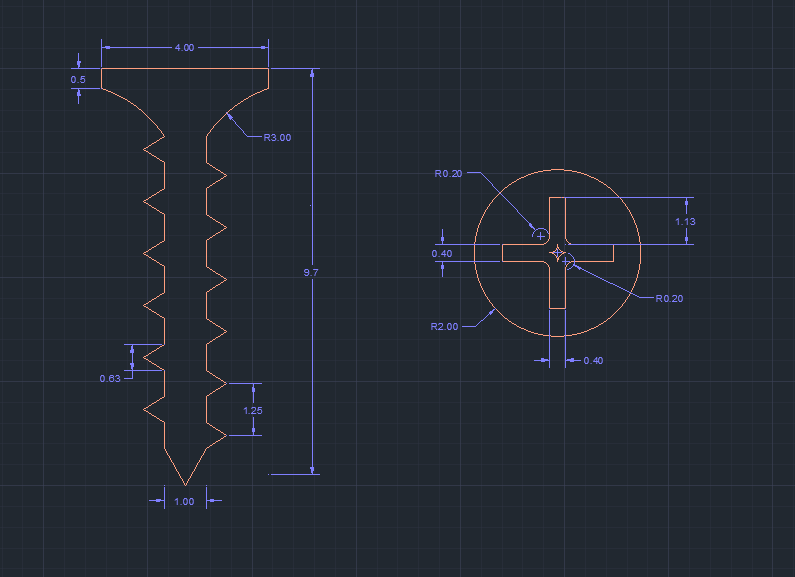
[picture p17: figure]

Figură 2.50. Șurub de fixare 2D

După ce am terminat schița 2D, am schimbat Worksapce-ul în 3D Basics și am schimbat

stratul de lucru ”Șurub 3D”. Zona care a fost în zig-zag, am construit-o cu funcția REVOLVE

(REVOLVE > Selectăm obiectul > Selectăm axa OY > 180° > Enter). Pentru partea de sus, am

utilizat comanda SWEEP (SWEEP > Selectăm cercul lateral > Enter > Selectăm cercul > Enter).

Pentru detalii, folosim funcția EXTRUDE (EXTRUDE > Selectăm dreptunghiurile > 0.5 > Space

> 0.2 > Enter).

Figură 2.51. Șurub de fixare 3D

### 2.3.10. Bară de presiune

Am schimbat Workspace-ul în Drafting & Annotation, am setat stratul ” Bară de presiune

2D ”. Cu ajutorul funcției RECTANGLE, am creat un dreptunghi, prima latură având lungimea de 2 cm, iar cea de-a doua 100 cm (RECTANGLE > 2 > Tab > 80 > Enter). Începând cu latura stângă

la o distanță de 5 cm, am făcut câte un cerc de rază 0.5 cm (CIRCLE > RADIUS > 0.5 > Enter). În total am făcut 20 de cerculețe.

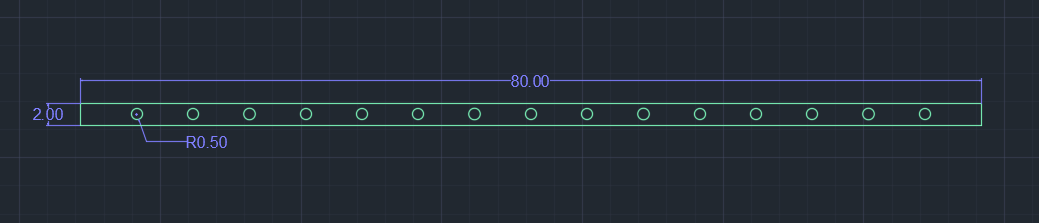
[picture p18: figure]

Figura 2.52. Bară de presiune 2D

După ce am terminat schița 2D, am schimbat Worksapce-ul în 3D Basics și am schimbat

stratul de lucru ”Bară de presiune 3D”. Am utilizat funcția PRESSPULL pentru a înălța obiectul și

a pastra găurile (PRESSPULL > Selectăm obiectul > 0.1 > Enter).

Figura 2.53. Bară de presiune 3D

### 2.3.11. Zăbrele de acordare

Am schimbat Workspace-ul în Drafting & Annotation, am setat stratul ” Zăbrele de acordare

2D ”. Pentru a face acest corp, a fost nevoie de două cercuri (CIRCLE > RADIUS > 1 > Enter),

(CIRCLE > RADIUS > 0.8 > Enter).

Figura 2.54. Zăbrele de acordare 2D

După ce am terminat schița 2D, am schimbat Worksapce-ul în 3D Basics și am schimbat

stratul de lucru ”Zăbrele de acordare 3D”. Inițial, am utilizat funcția EXTRUDE (EXTRUDE >

Selectăm cercurile > 0.5 > Space > 1 > Enter). Pentru ca obiectul din mijloc sa aibă un alt finisaț,

am făcut înca un cerc de rază 0.8 cm, pe care l-am taiat cu o linie pe axa OY și am utilizat funcția

REVOLVE (SWEEP > Selectăm cercul > Enter > Selectăm linia > Enter).

Figura 2.55. Zăbrele de acordare 3D

### 2.3.12. Punte lungă

Am schimbat Workspace-ul în Drafting & Annotation, am setat stratul ” Punte lungă 2D”.

Aceasta constă într-un dreptunghi mare, cu 88 de dreptunghiuri mici, dar pentru această parte a

proiectului am decis să includ doar acel mic dreptunghi, putând fi mai departe multiplicat, cu

ajutorul funcției PATH ARRAY. Așadar, am început cu un dreptunghi (RECTANGLE > 1 > Tab > 1.5 > Enter). În interiorul acestuia, la o distanță de 0.5 cm unul față de celălalt, am făcut 6 cercuri

de rază 0.1 cm (CIRCLE > RADIUS > 0.1 > Enter).

Figura 2.56. Punte lungă 2D

După ce am terminat schița 2D, am schimbat Worksapce-ul în 3D Basics și am schimbat

stratul de lucru ”Punte lungă 3D”. Pentru a delimita obiectul, am utilizat funcția BOUNDARY

(BOUNDARY > REGION > Selectăm mijlocul schiței > Enter). Pentru a face plăcuța, am utilizat

funcția EXTRUDE (EXTRUDE > Selectăm dreptunghiul > 0.1 > Enter). Pentru cerculețe am

folosit aceeași funcție EXTRUDE (EXTRUDE > Selectăm cercurile > 0.3 > Enter).

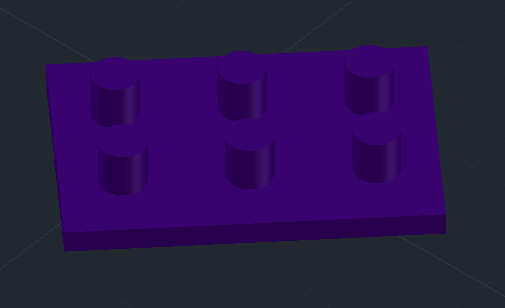
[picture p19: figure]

Figura 2.57. Punte lungă 3D

### 2.3.13. Pini ancorare

Am schimbat Workspace-ul în Drafting & Annotation, am setat stratul ” Pini de ancorare

2D ”. Pentru a face acest corp, a fost nevoie de un dreptunghi pentru vederea frontală

(RECTANGLE > 1 > Tab > 2 > Enter) și un cerc pentru vederea de sus (CIRCLE > RADIUS >0.5

> Enter).

Figura 2.58. Pini de ancorare 2D

După ce am terminat schița 2D, am schimbat Worksapce-ul în 3D Basics și am schimbat

stratul de lucru ”Pini de ancorare 3D”. Pentru a delimita obiectul, am utilizat funcția BOUNDARY

(BOUNDARY > REGION > Selectăm mijlocul schiței > Enter). Pentru a face obiectul, am utilizat

funcția EXTRUDE (EXTRUDE > Selectăm cercul > 2 > Enter).

Figura 2.59. Pini de ancorare 3D

### 2.3.14. Butoni de capstan

Am schimbat Workspace-ul în Drafting & Annotation, am setat stratul ” Mecanism de

acțiune 2D ”. Pentru a face acest corp, a fost nevoie de un dreptunghi pentru vederea frontală

(RECTANGLE > 1.5 > Tab > 3 > Enter) și un cerc în interiorul acestuia (CIRCLE > RADIUS >

0.1 > Enter) și un cerc pentru vederea de sus (CIRCLE > RADIUS > 0.75 > Enter). Schimbăm

stratul ”Material amortizator”. Pentru vederea frontală, facem încă un dreptunghi, deasupra

primului (RECTANGLE > 1.5 > Tab > 3 > Enter). Iar pentru vederea de sus, am făcut un cerc în

interiorul primului (CIRCLE > RADIUS > 0.7 > Enter).

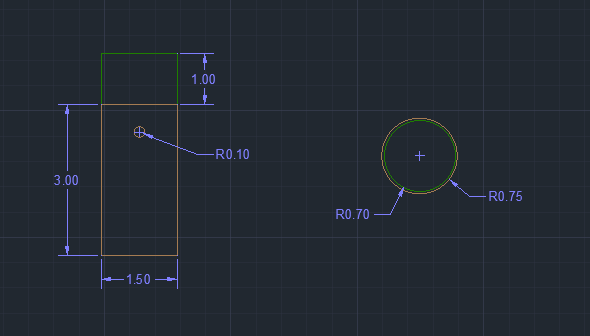
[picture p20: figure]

Figura 2.60. Butoni de capstan 2D

După ce am terminat schița 2D, am schimbat Worksapce-ul în 3D Basics și am schimbat

stratul de lucru ”mecanism de acțiune 3D”. Pentru a delimita obiectul, am utilizat funcția

BOUNDARY (BOUNDARY > REGION > Selectăm mijlocul schiței > Enter). Pentru a face

obiectul, am utilizat funcția EXTRUDE (EXTRUDE > Selectăm cercul mare > 3 > Enter),

(EXTRUDE > Selectăm cercul mic > 4 > Enter). Pentru a face găurile, am făcut 2 cerculete de

rază 0.1 cm, le-am inclus în obiect și am folosit SUBSTRACT (SUBSTRACT > Selectăm obiectul

> Selectăm cercurile > Enter).

Figura 2.61. Butoni de capstan 3D

### 2.3.15. Cadru

Am schimbat Workspace-ul în Drafting & Annotation, am setat stratul ” Cadru 2D ”. Pentru

a face acest corp, a fost nevoie de un dreptunghi (RECTANGLE > 116 > Tab > 146 > Enter). După

aceea, am început să construiesc piese aflate în acesta. Am făcut un triunghi, utilizând funcția

POLYLINE (POLYLINE > 65.3 > Space > 40 > Space > 30 > Enter). Pentru următoarele elemente am folosit aceeași funcție (POLYLINE > 25.9 > Space > 15 > Space > 15 > Enter), (POLYLINE

> 71.9 > Space > 63 > Space > 23 > Enter), continuând cu un cerc de rază 19.4 cm (CIRCLE >

RADIUS > 0.7 > Enter). Pentru restul am folosit doar funcția POLYLINE: (POLYLINE > 8.9 >

Space > 21 > Space > 16 > Space > 26 > Enter), (POLYLINE > 24.2 > Space > 19 > Space > 18

> Enter), (POLYLINE > 21.2 > Space > 14 > Space > 16 > Space > 18 > Enter), (POLYLINE >

21 > Space > 19 > Space > 12 > Enter). Pentru toate figurile am utilizat (FILLET > r > 3).

Figura 2.62. Cadru 2D

După ce am terminat schița 2D, am schimbat Worksapce-ul în 3D Basics și am schimbat

stratul de lucru ”Cadru 3D”. Pentru a delimita obiectul, am utilizat funcția BOUNDARY

(BOUNDARY > REGION > Selectăm mijlocul schiței > Enter). Pentru a face obiectul, am utilizat

funcția EXTRUDE (EXTRUDE > Selectăm obiectele > 10 > Enter), (EXTRUDE > Conturul

principal > 1 > Enter), (EXTRUDE > Selectăm punțile > 4 > Enter). După aceea, am substras

toate obiectele din contur folosit SUBSTRACT (SUBSTRACT > Selectăm conturul > Selectăm

obiectele > Enter).

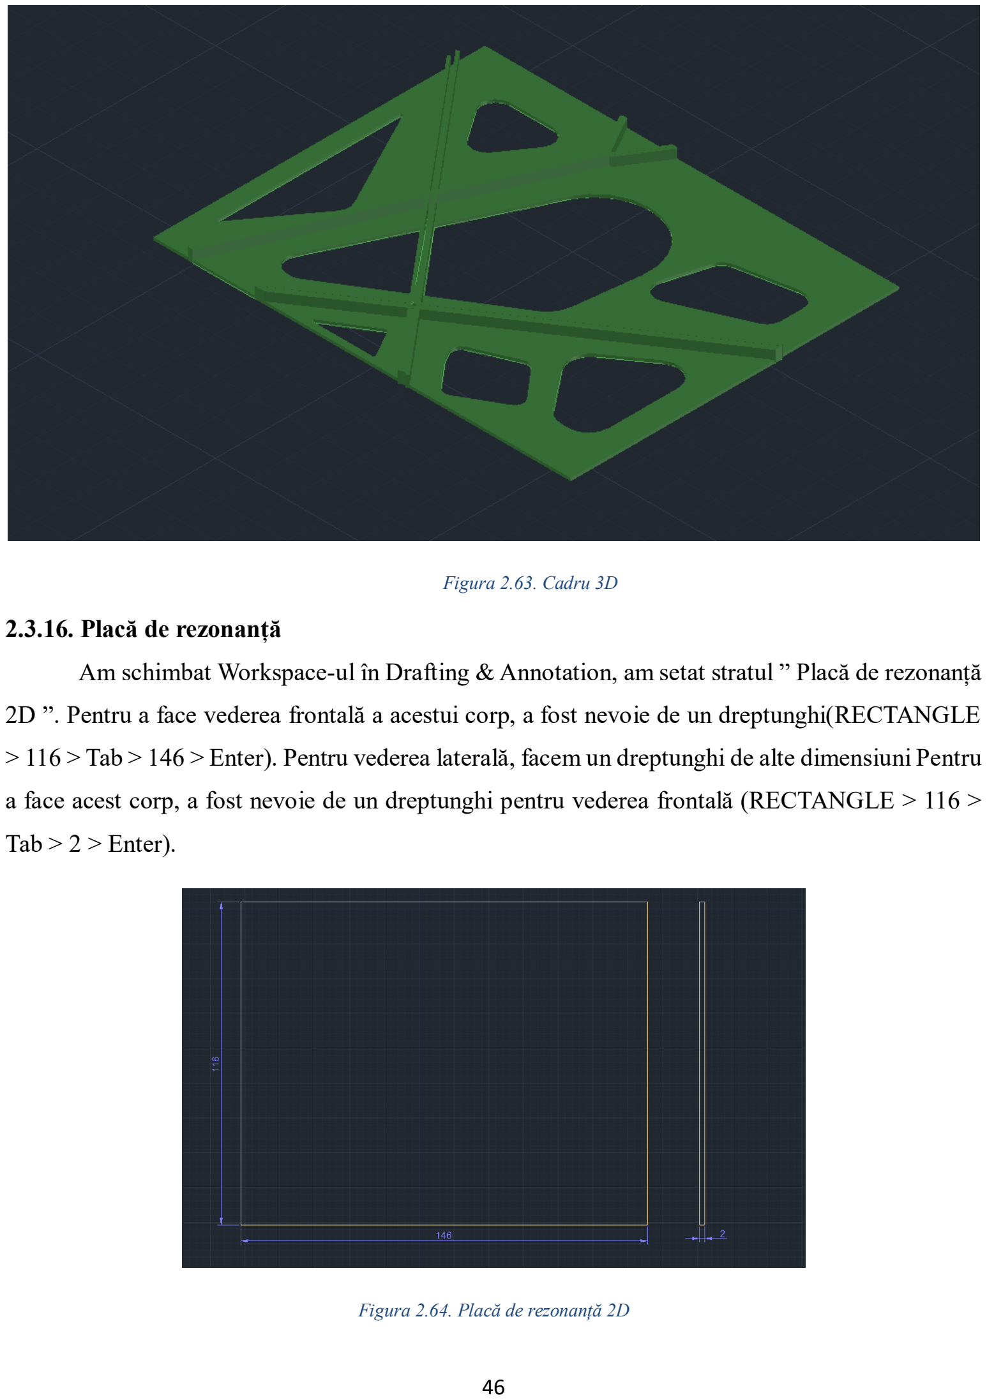
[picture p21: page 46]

Figura 2.63. Cadru 3D

### 2.3.16. Placă de rezonanță

Am schimbat Workspace-ul în Drafting & Annotation, am setat stratul ” Placă de rezonanță

2D ”. Pentru a face vederea frontală a acestui corp, a fost nevoie de un dreptunghi(RECTANGLE

> 116 > Tab > 146 > Enter). Pentru vederea laterală, facem un dreptunghi de alte dimensiuni Pentru

a face acest corp, a fost nevoie de un dreptunghi pentru vederea frontală (RECTANGLE > 116 >

Tab > 2 > Enter).

Figura 2.64. Placă de rezonanță 2D

După ce am terminat schița 2D, am schimbat Worksapce-ul în 3D Basics și am schimbat

stratul de lucru ”Placă de rezonanță 3D”. Pentru a delimita obiectul, am utilizat funcția

BOUNDARY (BOUNDARY > REGION > Selectăm mijlocul schiței > Enter). Pentru a face

obiectul, am utilizat funcția EXTRUDE (EXTRUDE > Selectăm obiectul > 2 > Enter).

Figura 2.65. Placă de rezonanță 3D

### 3. Ansamblu componente interne

Inițial, am luat placa de rezonanță și cadrul, dupa aceea le-am unit. Ulterior, am adăugat și bara

de presiune. Un prim pas important pe care l-am făcut, pentru ca acest ansamblu să ia contur, am

utilizat mecanismul de acțiune. Am copiat figura, am utilizat funcția 3DROTATE (Selectăm

obiectul > Apelăm funcția 3DROTATE > Ridicăm pe verticală la 90° > Enter). Am unit configurația

cu butonii de capstan și am unit tot acest obiect solid. După aceea, cu ajutorul funcției

PATHARRAY, am făcut 88 de astfel de mecanisme, rezultatul fiind vizibil în Figura 3.1.

Figura 3.1. Mecanism de acțiune integrat

După ce am finalizat această acțiune, am început să adaug și restul componentelor, precum:

corzile, zăbrelele de acordare, puntea lungă și pinii de acordare. Pentru ca toate aceste elemente sa

fie amplasate în cadru, am utilizat funcții precum PATH ARRAY, RECTANGULAR ARRAY,

COPY, MOVE, rezultatul putând fi observat în Figura 3.2.

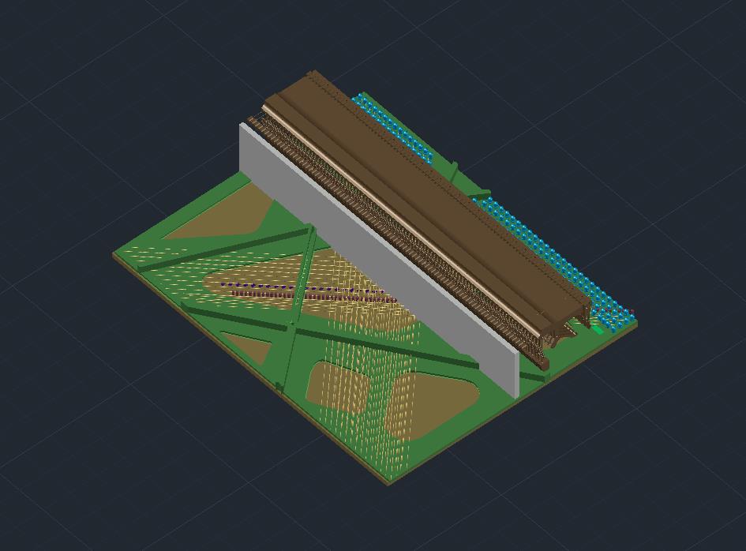
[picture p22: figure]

Figura 3.2. Ansamblu componente interne

### 4. Viziune laterală

Am făcut viziunea laterală a pianinei, folosind toate componentele din 2D, care pot fi văzute

din partea laterală a unui pian. Funcțiile folosite au fost COPY și MOVE.

Figură 4.4.1. Viziune laterală

### 5. Viziune frontală

Am făcut viziunea frontală a pianinei, folosind toate componentele din 2D, care pot fi văzute

din partea frontală a unui pian. Funcțiile folosite au fost COPY și MOVE.

Figura 5.1. Viziune frontală

### 6. Viziune de sus

Am făcut viziunea de sus a pianinei, folosind toate componentele din 2D, care pot fi văzute din

partea de sus a unui pian. Funcțiile folosite au fost COPY și MOVE.

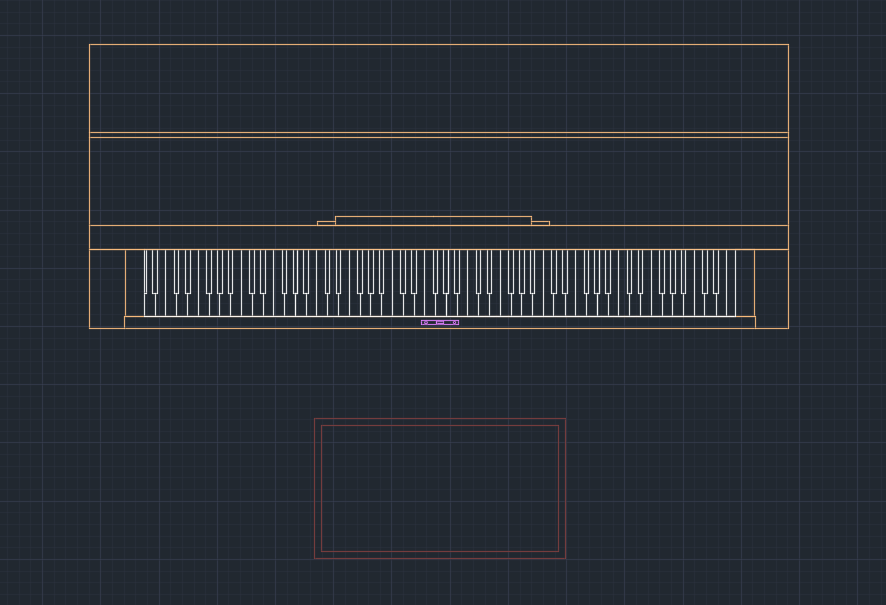
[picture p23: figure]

Figura 6.1. Viziunea de sus

### 7. Ansamblu final pianină

Pentru a realiza ansamblul de final, am utilizat toate componentele externe, pe care le-am

alăturat cu ajutorul funcțiilor MOVE, COPY, PATH ARRAY. Aceste componente reunite pot fi

observate în figura 7.1. Dar, pentru că pianul nu constă doar într-o carcasă, am alăturat acestui

ansamblu și componentele interne, legate anterior.

Figura 7.1 Ansamblu componente externe pianină

Am început prin utilizarea funcției UNION, pentru a reuni tot ansamblul de componente

interne, această acțiune putând fi observată în figura 7.2.

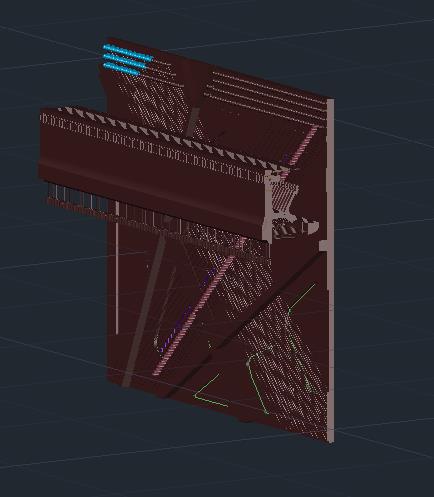
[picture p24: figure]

Figură 7.2Uniunea componentelor interne

Pentru a finaliza, am utilizat funcția MOVE, și am unit cele 2 ansambluri, formând o entitate

deplină – pianina.

Figura 7.3. Ansamblu final pianină

### 8. Concluzii

În calitate de inginer, cunoașterea activităților de proiectare în diverse programe de lucru

este esențială, iar AutoCAD se remarcă ca fiind unul dintre cele mai populare și utilizate

instrumente de grafică asistată de calculator.

Am ales să realizez acest proiect, datorită pasiunii mele pentru muzică și în special pentru

instrumental muzical – pianina. Pe parcursul proiectului, am avut ocazia să mă familiarizez cu

funcțiile avansate ale aplicației AutoCAD, să explorez detaliile tehnice ale pianinei și să înțeleg cât

de semnificative sunt toate componentele acesteia. Proiectarea unei pianine nu a implicat doar

utilizarea abilităților tehnice, ci și înțelegerea profundă a structurii și mecanismelor acestui

instrument muzical complex.

Am început cu realizarea schițelor tehnice în 2D, asigurându-mă că fiecare parte este precis

dimensionată. Ulterior, am trecut la modelarea 3D, unde am putut vizualiza și ajusta fiecare detaliu

al pianinei.

Prin acest proiect, nu numai că am reușit să creez un model detaliat și funcțional al unei

pianine, dar am și aprofundat cunoștințele mele în inginerie și grafică asistată de calculator.

Bibliografie

[1] Sound Creation. Yamaha U1 Pianină.

https://www.soundcreation.ro/pianine-cid536_3112/yamaha-u1-q-pm-

id15041.html?utm_campaign=2Performant&utm_source=bd86b03fc&utm_medium=CPS (https://www.soundcreation.ro/pianine-cid536_3112/yamaha-u1-q-pm-id15041.html)

[2] Reverb. Pianoforte a Coda Yamaha Grand Piano C3.

https://reverb.com/item/40116024-pianoforte-a-coda-yamaha-grand-piano-c3-stmipe

[3]Castelul Peleș. Pianul Girafa.

https://peles.ro/patrimoniul/instrumente-muzicale/pianul-girafa/

- BrainyQuote. Tom Lehrer Quotes.

https://www.brainyquote.com/authors/tom-lehrer-quotes

- CyberLeninka. Как и для чего создавалось пианино.

https://cyberleninka.ru/article/n/kak-i-dlya-chego-sozdavalos-pianino

- Nanoton. Корпус пианино.

https://nanoton.su/korp_pianino.html

- Archive.org. Encyclopedia of Automatic Musical Instruments.

https://archive.org/details/encyclopediaofau0000bowe/page/n1/mode/2up

- Howard Piano Industries. Upright Piano Whippen.

https://www.howardpianoindustries.com/upright-piano-whippen/

- Yamaha. Yamaha Upright Piano Buyers Guide.

https://uk.yamaha.com/en/files/Yamaha_Upright_Piano_Buyers_Guide_EN_16092020_3d80af2a

f9ce2df3e607f2996da6c943.pdf (https://uk.yamaha.com/en/files/Yamaha_Upright_Piano_Buyers_Guide_EN_16092020_3d80af2af9ce2df3e607f2996da6c943.pdf)

- Miller's Music. The Anatomy of an Upright Piano.

https://millersmusic.co.uk/blogs/blog/the-anatomy-of-an-upright-piano

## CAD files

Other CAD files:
Componente externe/Clapă albă 2D + Clapă neagră 2D.dwg
Componente interne/Linguriță amortizatoare 2D.dwg
Viziune frontală.dwg
Ansamblu componente interne.dwg
Componente externe/Picior 3D.dwg
Componente interne/Linguriță amortizatoare 3D.dwg
Componente externe/Pedală 3D.dwg
Componente interne/Punte lungă 3D.dwg
Viziune laterală pianina.dwg
Ansamblu componente externe.dwg
Componente externe/Clapă albă 3D + Clapă neagră 3D.dwg
Componente interne/Ciocănele 2D.dwg
Componente externe/Capac.dwg
Componente interne/Mecanism de reținere 2D.dwg
Viziune de sus.dwg
Componente externe/Placă laterală 2D.dwg
Componente interne/Pini de ancorare 3D.dwg
Componente externe/Placa superioară.dwg
Componente externe/Bloc de clape 2D.dwg
Componente externe/Bloc de clape 3D.dwg
Componente externe/Bloc de picior 2D.dwg
Componente externe/Bloc de picior 3D.dwg
Componente externe/Braț lateral 2D.dwg
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
